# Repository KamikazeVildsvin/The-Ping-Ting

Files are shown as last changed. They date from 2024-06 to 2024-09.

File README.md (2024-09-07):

# The Ping Ting
This repository contains the KiCad files and the design files for *The Ping Ting*.

The Ping Ting is a single PCB with three different high-Q state variable filters, which are intended to be used for "filter pinging".
The board can be supplied from a typical 9V-12V DC center positive power supply.

## Images

### 3D Model
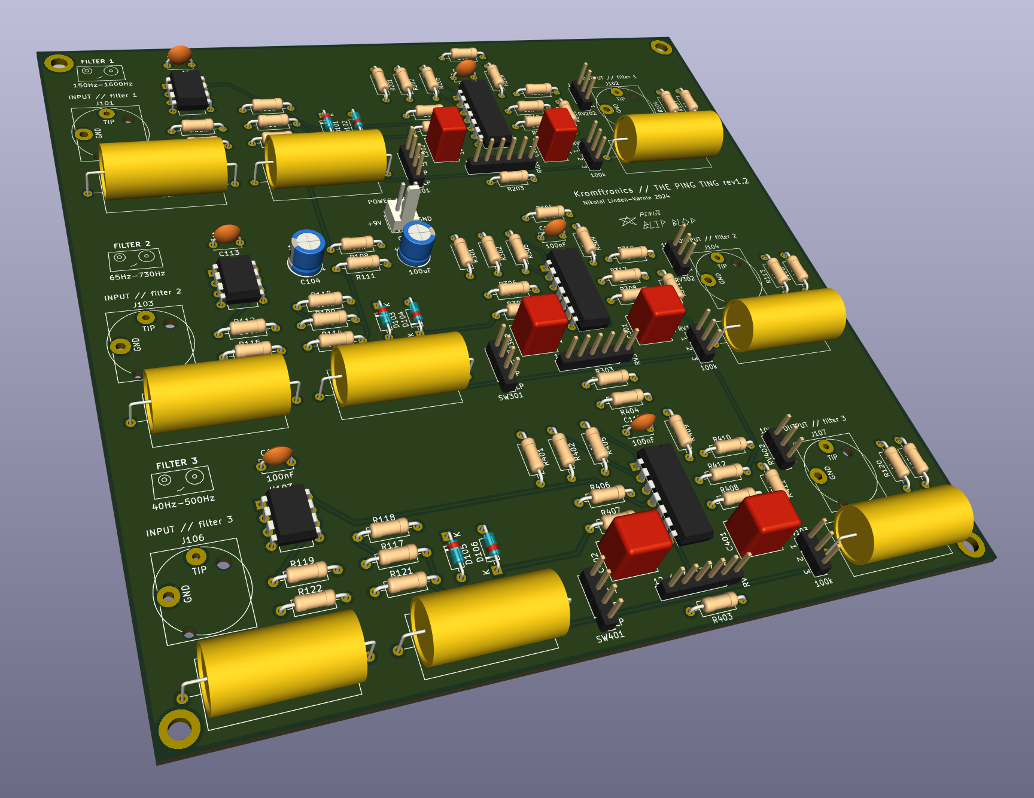
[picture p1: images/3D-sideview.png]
3D-sideview


### PCB
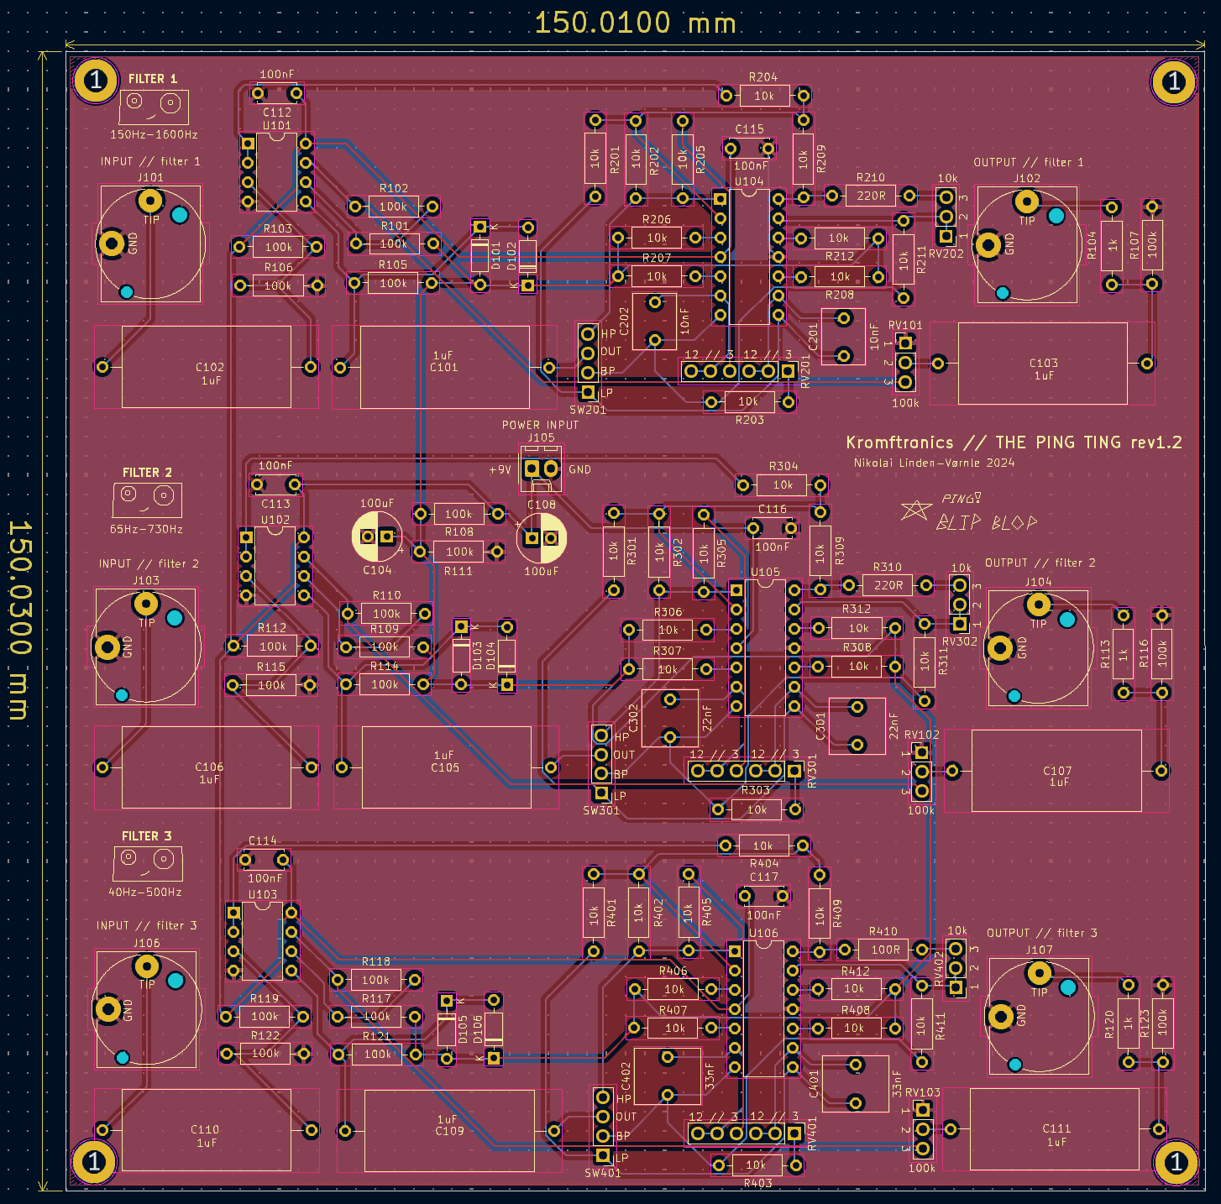
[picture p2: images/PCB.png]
PCB


### Schematic
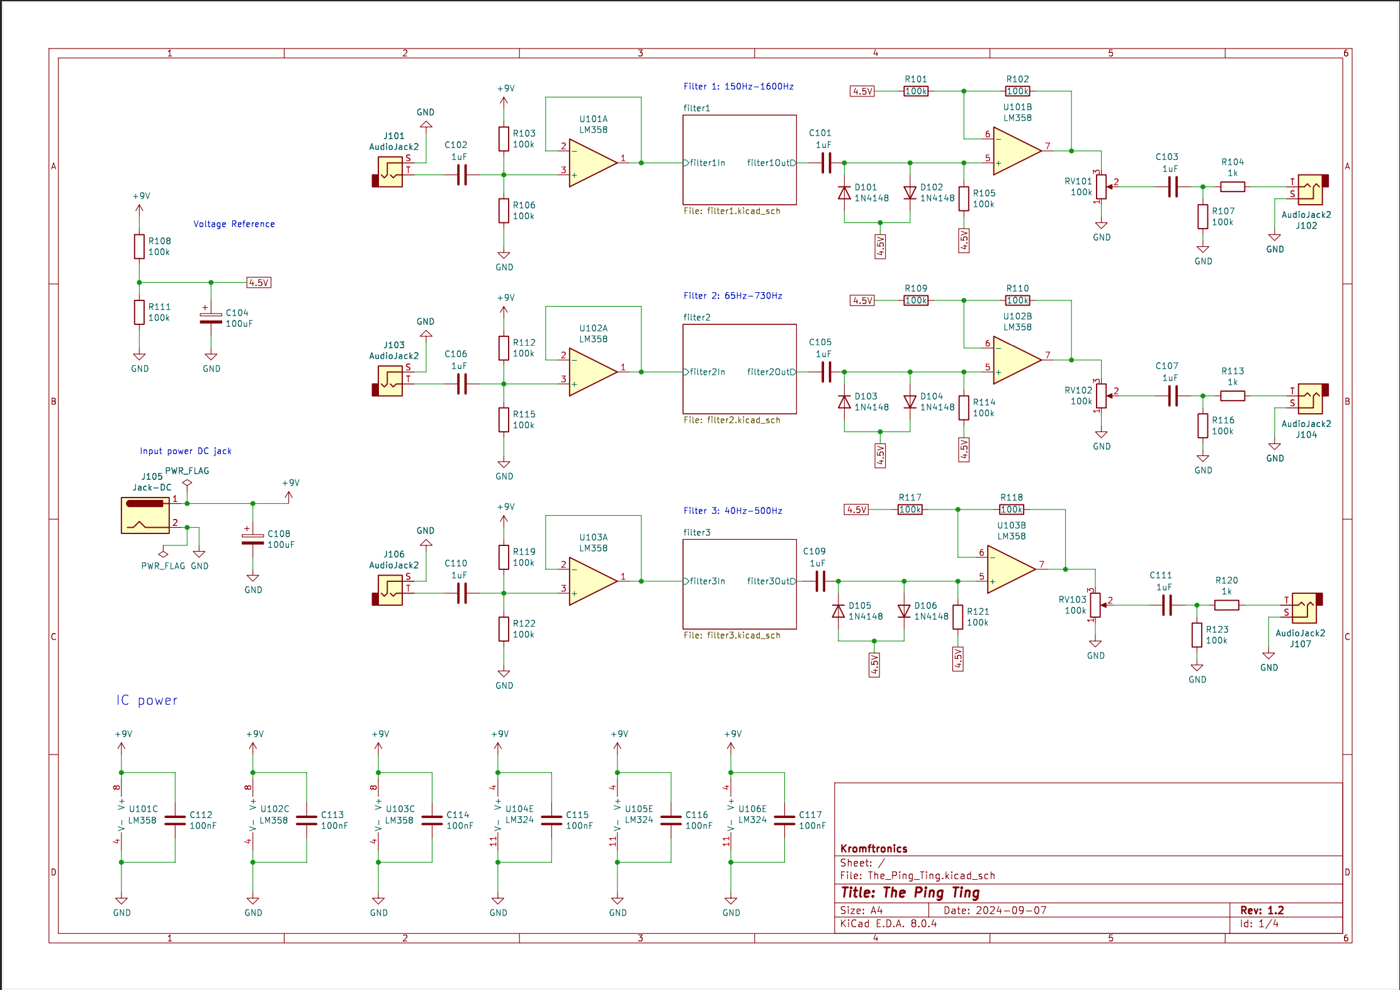
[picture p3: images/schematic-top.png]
schematic


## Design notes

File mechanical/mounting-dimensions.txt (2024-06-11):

Dimensioner til huller:

(1) Rotary Switch: 11mm

(2) Frequency Pot: 7.5mm

(3) Resonans Pot: 7.5mm

(4) Volume Pot: 11mm

Layout - ift. metalpladen

(1) (2) (3) (4)

(1) (2) (3) (4)

(1) (2) (3) (4)

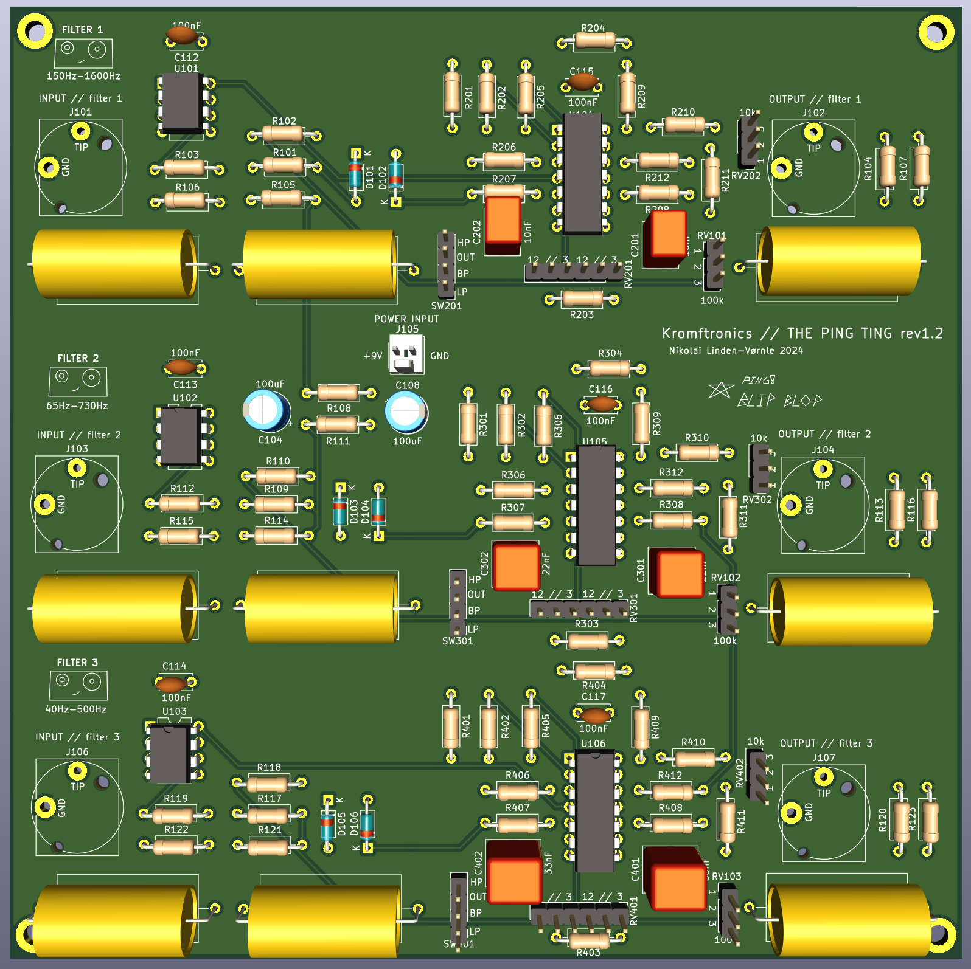
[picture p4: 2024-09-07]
images/3D.png

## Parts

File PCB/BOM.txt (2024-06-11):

BOM - The Ping Ting

LM342 [4x rail-to-rail opamps]

LM358 [2x rail-to-rail opamps]

Dual 100kOhm log potentiometer

resistors

film/ceramic caps

1P3T switches (Banzei mangler en)

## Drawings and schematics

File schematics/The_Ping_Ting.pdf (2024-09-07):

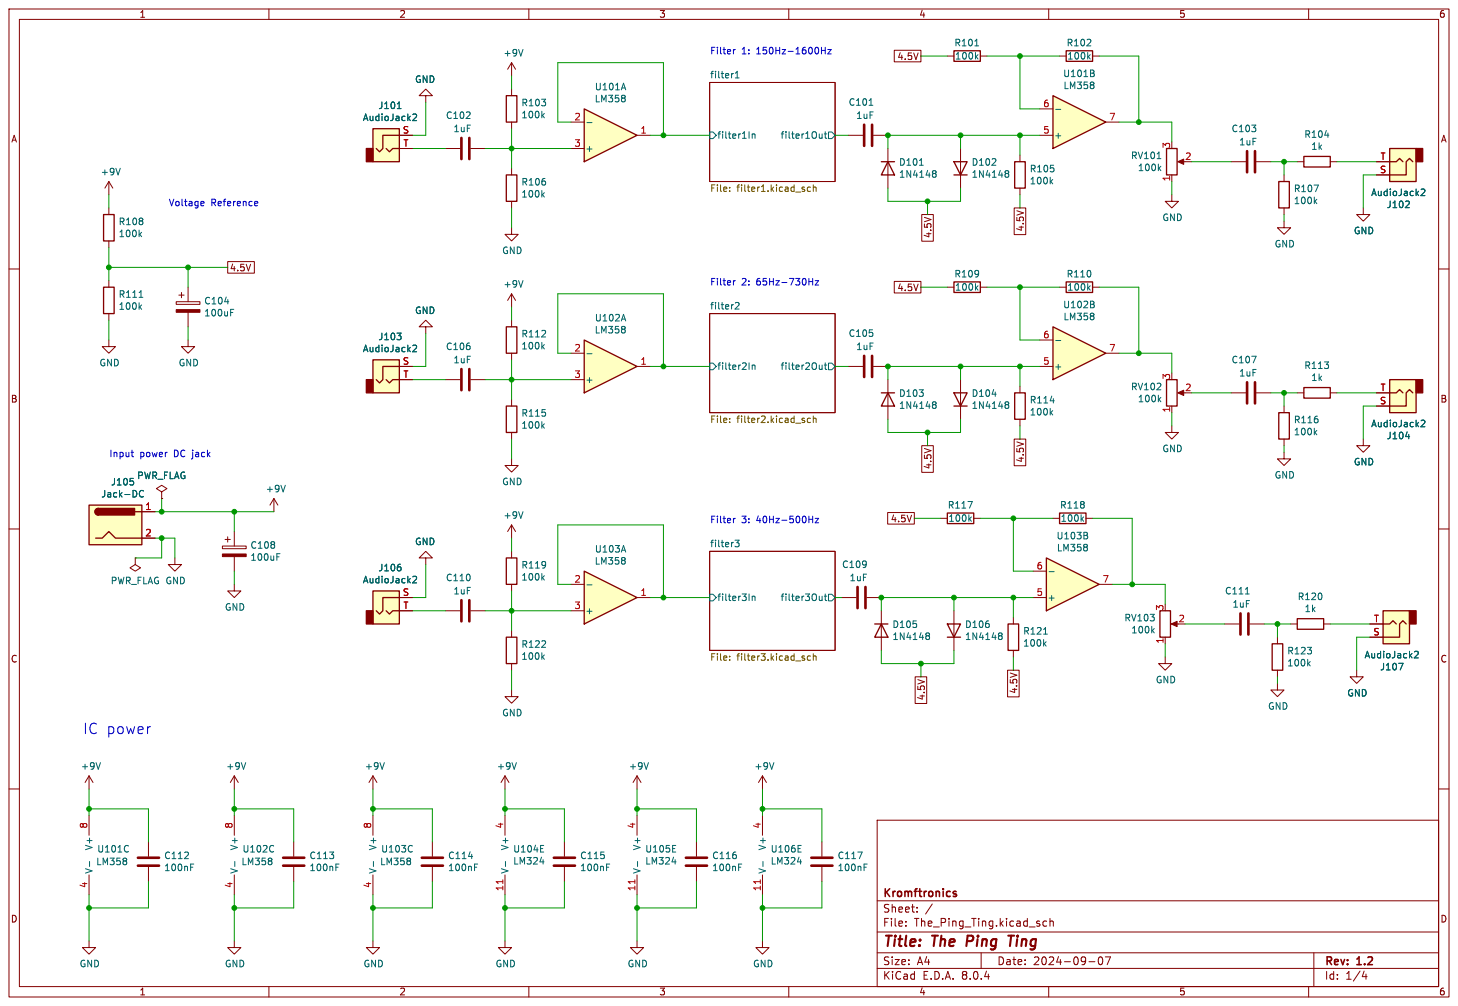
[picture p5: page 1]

Filter 2: 65Hz-730Hz Filter 3: 40Hz-500Hz Voltage Reference

Input power DC jack

Id: 1/4 Title: The Ping Ting

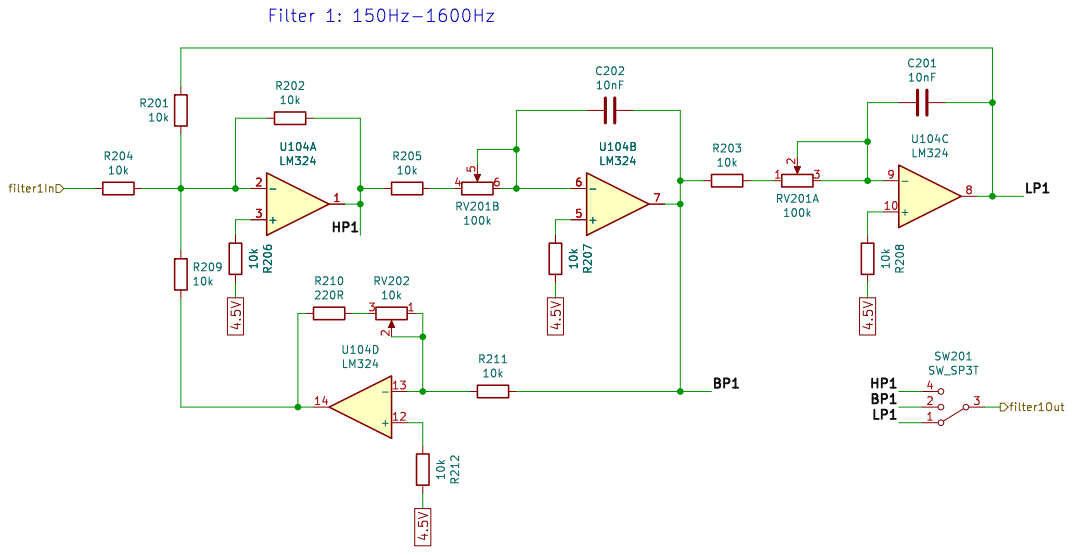
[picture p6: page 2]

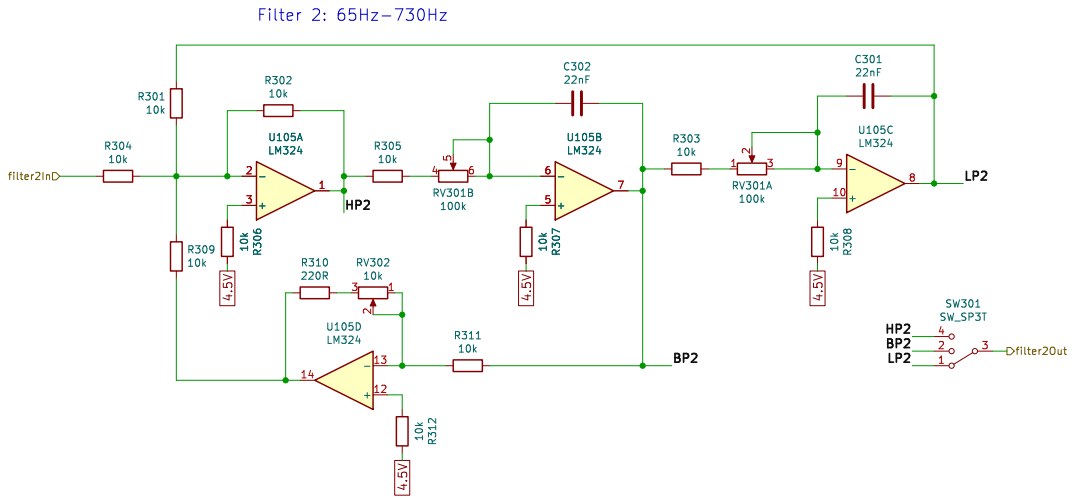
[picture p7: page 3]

Id: 3/4 Title: Mid Frequency Filter File: filter2.kicad_sch Sheet: /filter2/ Kromftronics

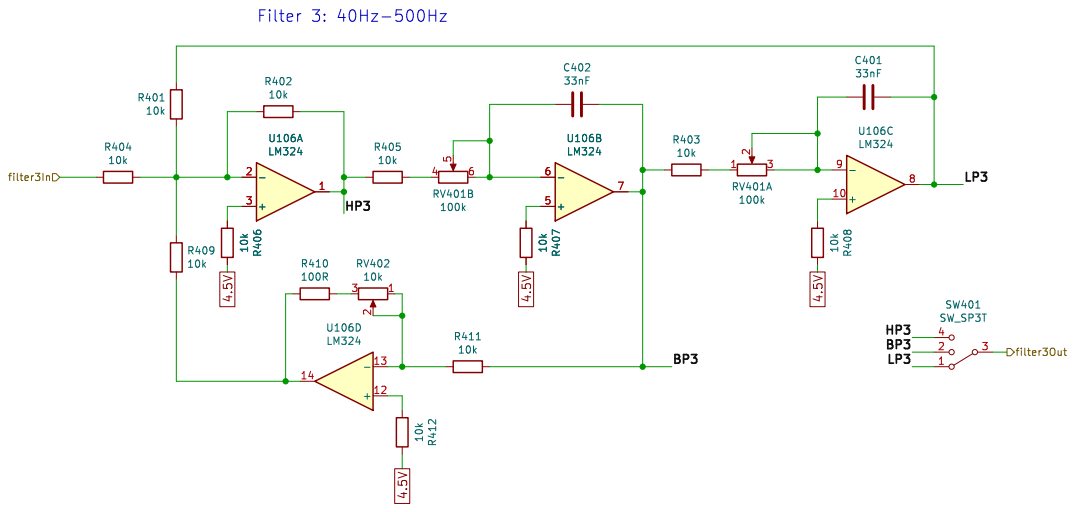
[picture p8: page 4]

Id: 4/4 Title: Low Frequency Filter File: filter3.kicad_sch Sheet: /filter3/ Kromftronics

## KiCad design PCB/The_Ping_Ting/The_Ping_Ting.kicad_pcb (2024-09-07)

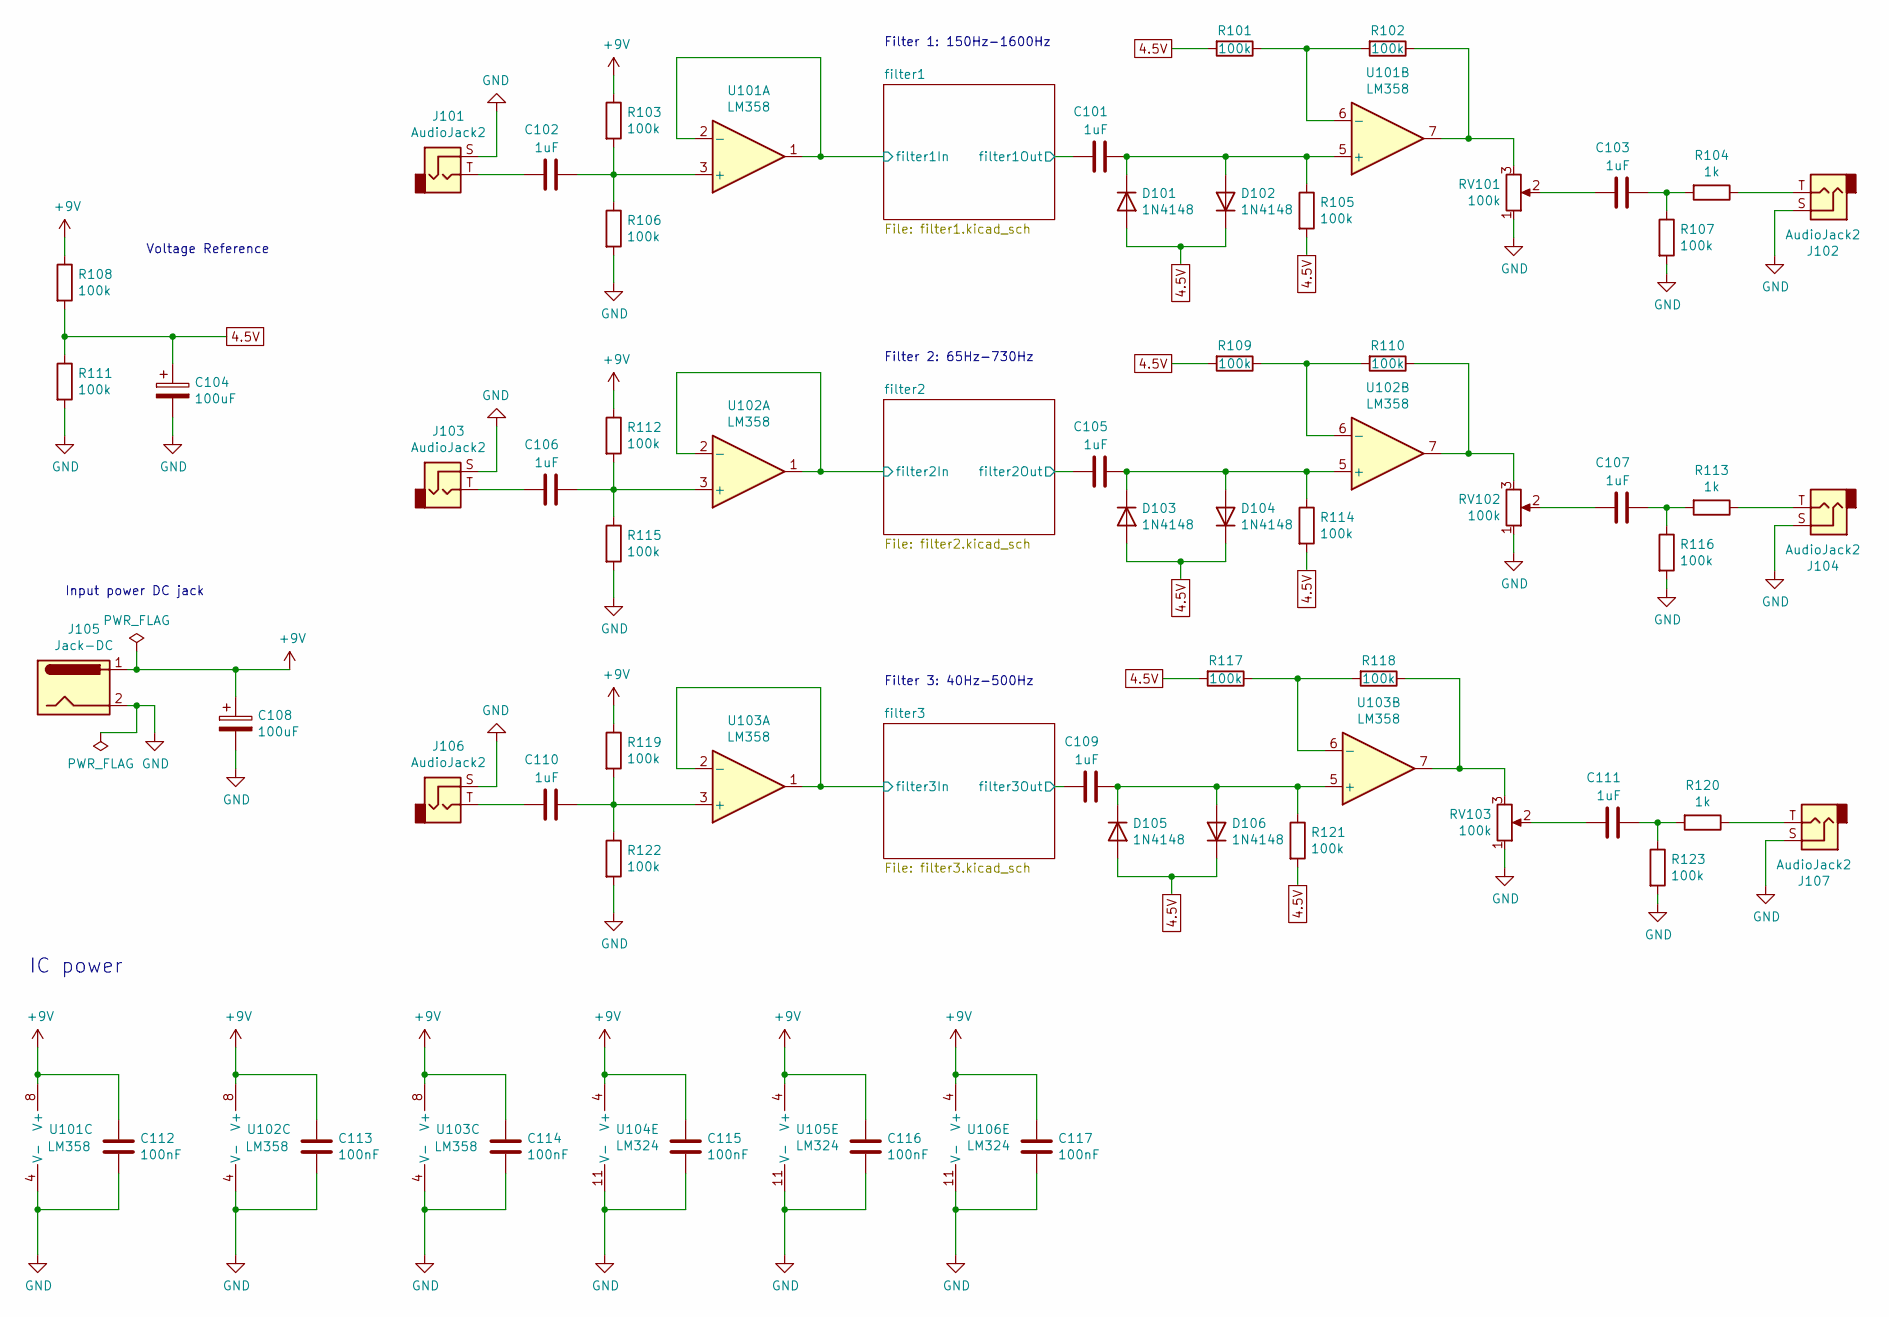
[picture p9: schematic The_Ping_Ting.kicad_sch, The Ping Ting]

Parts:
C101, C102, C103, C105, C106, C107, C109, C110, C111: 1uF; C_Axial_L22.0mm_D10.5mm_P27.50mm_Horizontal
C104, C108: 100uF; CP_Radial_D6.3mm_P2.50mm
C112, C113, C114, C115, C116, C117: 100nF; C_Disc_D5.0mm_W2.5mm_P5.00mm
D101, D102, D103, D104, D105, D106: 1N4148; D_DO-35_SOD27_P7.62mm_Horizontal
J101, J102, J103, J104, J106, J107: AudioJack2; Jack_6.35mm_Neutrik_NJ2FD-V_Vertical
J105: Jack-DC; Molex_KK-254_AE-6410-02A_1x02_P2.54mm_Vertical
R101, R102, R103, R105, R106, R107, R108, R109, R110, R111, R112, R114, R115, R116, R117, R118, R119, R121, R122, R123: 100k; R_Axial_DIN0207_L6.3mm_D2.5mm_P10.16mm_Horizontal
R104, R113, R120: 1k; R_Axial_DIN0207_L6.3mm_D2.5mm_P10.16mm_Horizontal
RV101, RV102, RV103: 100k; PinHeader_1x03_P2.54mm_Vertical
U101, U102, U103: LM358; DIP-8_W7.62mm
U104, U105, U106: LM324; DIP-14_W7.62mm

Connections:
4.5V: C104.1, D101.2 (A), D102.1 (K), D103.2 (A), D104.1 (K), D105.2 (A), D106.1 (K), R101.2, R105.2, R108.2, R109.2, R111.1, R114.2, R117.2, R121.2; also elsewhere on the board
+9V: C108.1, C112.1, C113.1, C114.1, C115.1, C116.1, C117.1, J105.1, R103.1, R108.1, R112.1, R119.1, U101.8 (V+), U102.8 (V+), U103.8 (V+), U104.4 (V+), U105.4 (V+), U106.4 (V+)
/filter1/filter1In: U101.1, U101.2 (-); also elsewhere on the board
/filter1/filter1Out: C101.1; also elsewhere on the board
/filter2/filter2In: U102.1, U102.2 (-); also elsewhere on the board
/filter2/filter2Out: C105.1; also elsewhere on the board
/filter3/filter3In: U103.1, U103.2 (-); also elsewhere on the board
/filter3/filter3Out: C109.1; also elsewhere on the board
GND: C104.2, C108.2, C112.2, C113.2, C114.2, C115.2, C116.2, C117.2, J101.S, J102.S, J103.S, J104.S, J105.2, J106.S, J107.S, R106.2, R107.2, R111.2, R115.2, R116.2, R122.2, R123.2, RV101.1, RV102.1, RV103.1, U101.4 (V-), U102.4 (V-), U103.4 (V-), U104.11 (V-), U105.11 (V-), U106.11 (V-)
unnamed: C102.1, J101.T
unnamed: C103.1, RV101.2
unnamed: C103.2, R104.2, R107.1
unnamed: C106.1, J103.T
unnamed: C107.1, RV102.2
unnamed: C107.2, R113.2, R116.1
unnamed: C110.1, J106.T
unnamed: C111.1, RV103.2
unnamed: C111.2, R120.2, R123.1
unnamed: C101.2, D101.1 (K), D102.2 (A), R105.1, U101.5 (+)
unnamed: C105.2, D103.1 (K), D104.2 (A), R114.1, U102.5 (+)
unnamed: C109.2, D105.1 (K), D106.2 (A), R121.1, U103.5 (+)
unnamed: J102.T, R104.1
unnamed: J104.T, R113.1
unnamed: J107.T, R120.1
unnamed: R102.1, RV101.3, U101.7
unnamed: R110.1, RV102.3, U102.7
unnamed: R118.1, RV103.3, U103.7
unnamed: C102.2, R103.2, R106.1, U101.3 (+)
unnamed: R101.1, R102.2, U101.6 (-)
unnamed: C106.2, R112.2, R115.1, U102.3 (+)
unnamed: R109.1, R110.2, U102.6 (-)
unnamed: C110.2, R119.2, R122.1, U103.3 (+)
unnamed: R117.1, R118.2, U103.6 (-)

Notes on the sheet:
Filter 1: 150Hz-1600Hz
IC power
Input power DC jack
Filter 3: 40Hz-500Hz
Filter 2: 65Hz-730Hz
Voltage Reference

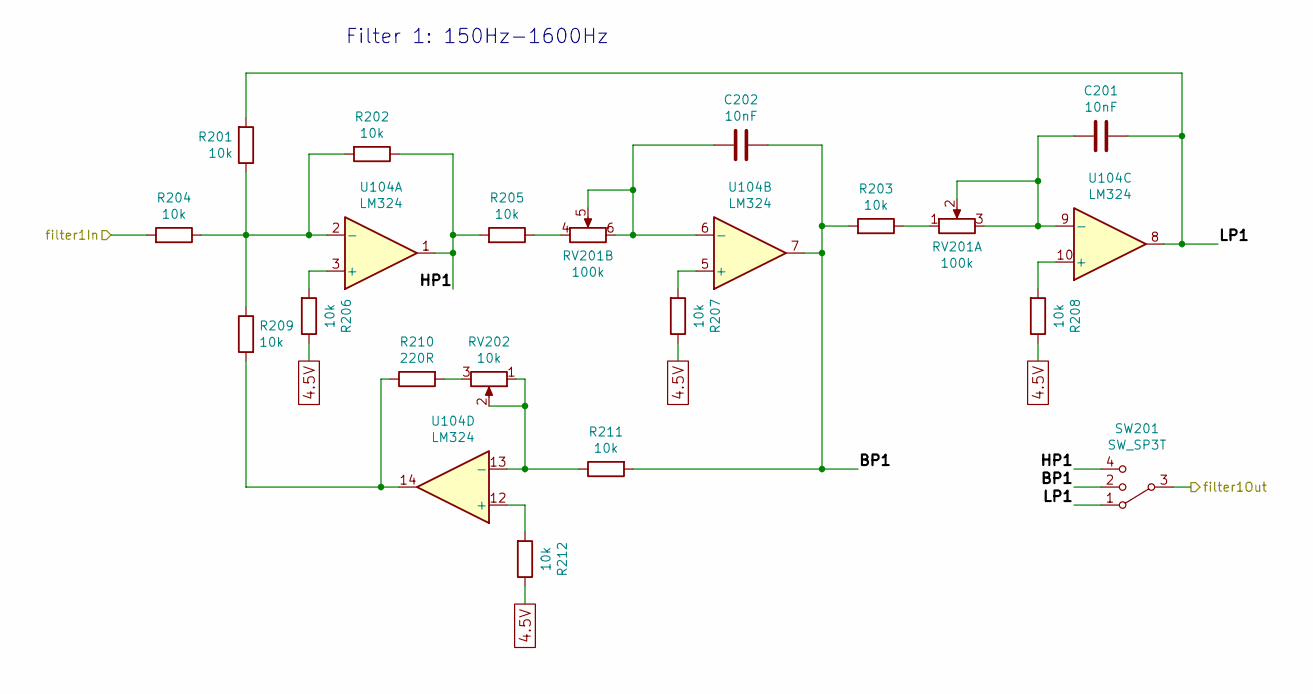
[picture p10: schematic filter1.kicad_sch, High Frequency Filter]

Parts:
C201, C202: 10nF; C_Rect_L7.2mm_W5.5mm_P5.00mm_FKS2_FKP2_MKS2_MKP2
R201, R202, R203, R204, R205, R206, R207, R208, R209, R211, R212: 10k; R_Axial_DIN0207_L6.3mm_D2.5mm_P10.16mm_Horizontal
R210: 220R; R_Axial_DIN0207_L6.3mm_D2.5mm_P10.16mm_Horizontal
RV201: 100k; PinHeader_1x06_P2.54mm_Vertical
RV202: 10k; PinHeader_1x03_P2.54mm_Vertical
SW201: SW_SP3T; PinHeader_1x04_P2.54mm_Vertical
U104: LM324; DIP-14_W7.62mm

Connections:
4.5V: R206.1, R207.1, R208.1, R212.1; also elsewhere on the board
/filter1/BP1: C202.1, R203.2, R211.2, SW201.2, U104.7
/filter1/HP1: R202.1, R205.2, SW201.4, U104.1
/filter1/LP1: C201.1, R201.2, SW201.1, U104.8
/filter1/filter1In: R204.2; also elsewhere on the board
/filter1/filter1Out: SW201.3; also elsewhere on the board
unnamed: R203.1, RV201.1
unnamed: R205.1, RV201.4
unnamed: R209.2, R210.1, U104.14
unnamed: R210.2, RV202.3
unnamed: R206.2, U104.3 (+)
unnamed: R201.1, R202.2, R204.1, R209.1, U104.2 (-)
unnamed: R207.2, U104.5 (+)
unnamed: C202.2, RV201.5, RV201.6, U104.6 (-)
unnamed: R208.2, U104.10 (+)
unnamed: C201.2, RV201.2, RV201.3, U104.9 (-)
unnamed: R212.2, U104.12 (+)
unnamed: R211.1, RV202.1, RV202.2, U104.13 (-)

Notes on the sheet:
Filter 1: 150Hz-1600Hz

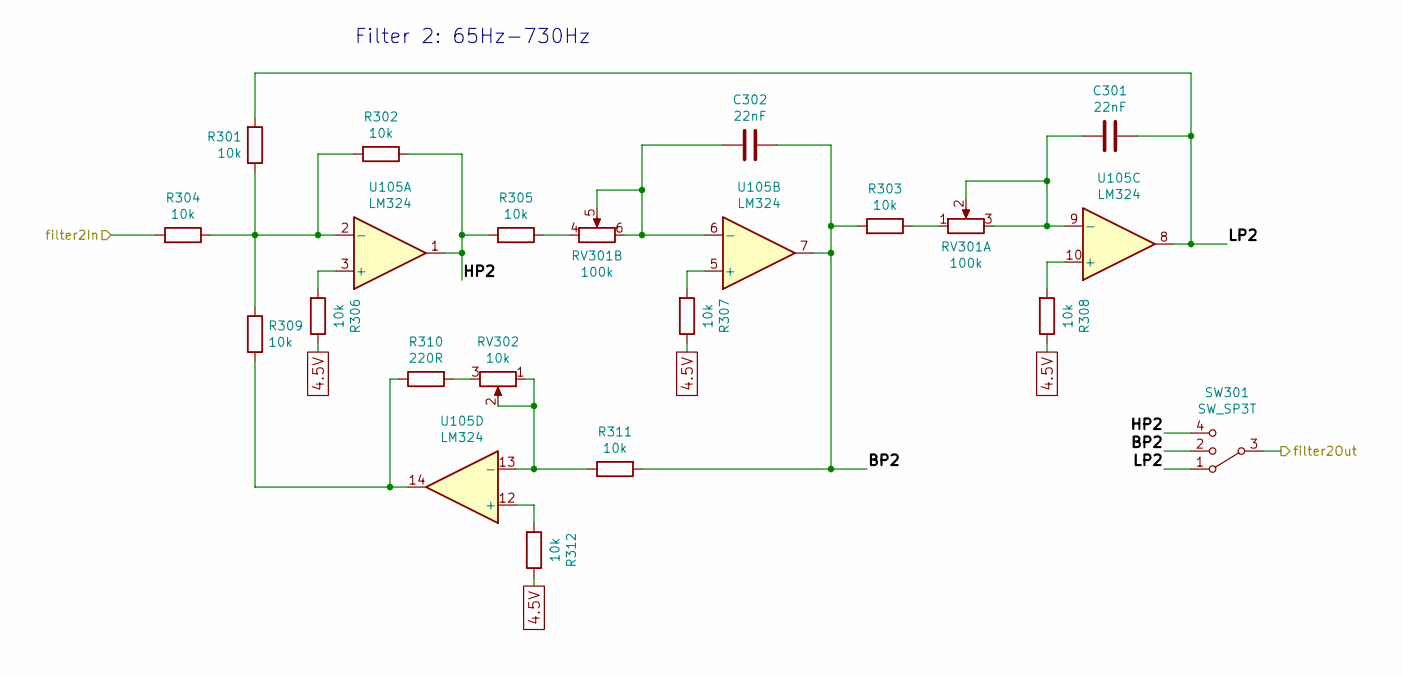
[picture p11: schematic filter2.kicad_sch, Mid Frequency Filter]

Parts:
C301, C302: 22nF; C_Rect_L7.2mm_W7.2mm_P5.00mm_FKS2_FKP2_MKS2_MKP2
R301, R302, R303, R304, R305, R306, R307, R308, R309, R311, R312: 10k; R_Axial_DIN0207_L6.3mm_D2.5mm_P10.16mm_Horizontal
R310: 220R; R_Axial_DIN0207_L6.3mm_D2.5mm_P10.16mm_Horizontal
RV301: 100k; PinHeader_1x06_P2.54mm_Vertical
RV302: 10k; PinHeader_1x03_P2.54mm_Vertical
SW301: SW_SP3T; PinHeader_1x04_P2.54mm_Vertical
U105: LM324; DIP-14_W7.62mm

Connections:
4.5V: R306.1, R307.1, R308.1, R312.1; also elsewhere on the board
/filter2/BP2: C302.1, R303.2, R311.2, SW301.2, U105.7
/filter2/HP2: R302.1, R305.2, SW301.4, U105.1
/filter2/LP2: C301.1, R301.2, SW301.1, U105.8
/filter2/filter2In: R304.2; also elsewhere on the board
/filter2/filter2Out: SW301.3; also elsewhere on the board
unnamed: R303.1, RV301.1
unnamed: R305.1, RV301.4
unnamed: R309.2, R310.1, U105.14
unnamed: R310.2, RV302.3
unnamed: R306.2, U105.3 (+)
unnamed: R301.1, R302.2, R304.1, R309.1, U105.2 (-)
unnamed: R307.2, U105.5 (+)
unnamed: C302.2, RV301.5, RV301.6, U105.6 (-)
unnamed: R308.2, U105.10 (+)
unnamed: C301.2, RV301.2, RV301.3, U105.9 (-)
unnamed: R312.2, U105.12 (+)
unnamed: R311.1, RV302.1, RV302.2, U105.13 (-)

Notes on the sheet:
Filter 2: 65Hz-730Hz

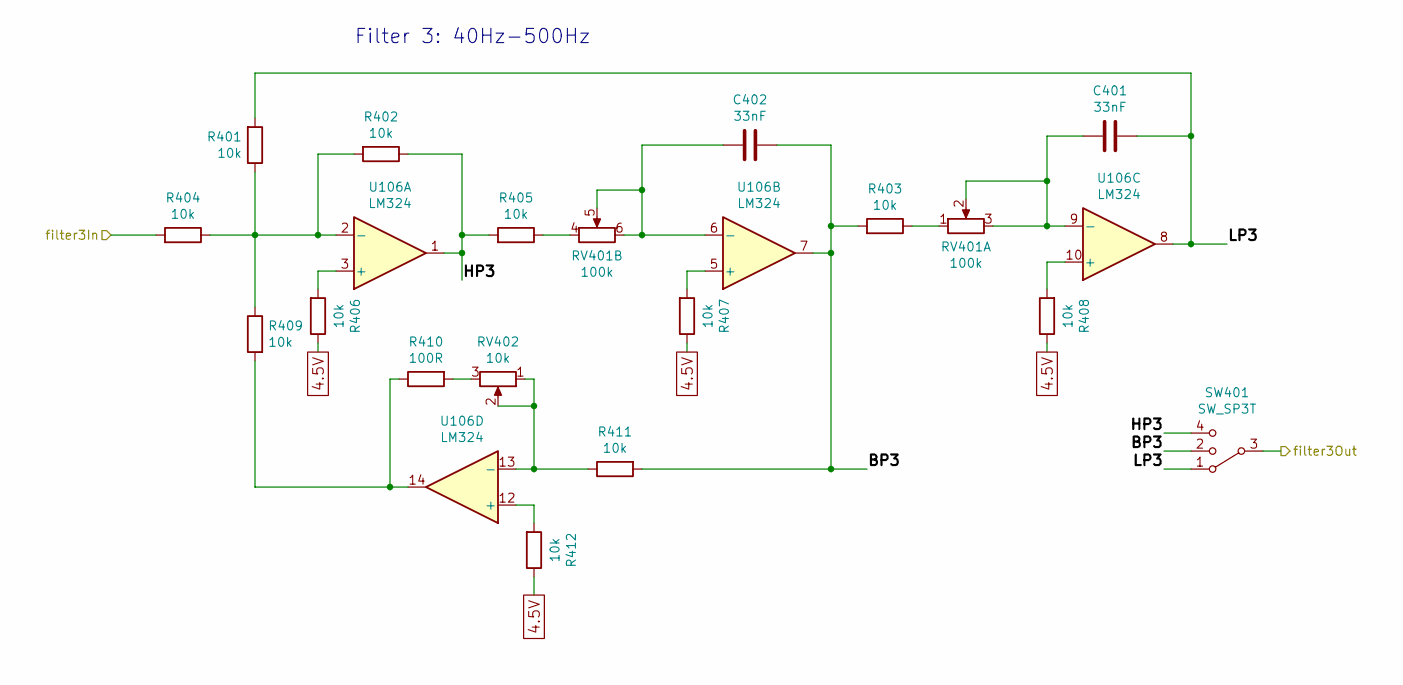
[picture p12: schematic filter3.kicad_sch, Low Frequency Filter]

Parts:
C401, C402: 33nF; C_Rect_L7.2mm_W8.5mm_P5.00mm_FKP2_FKP2_MKS2_MKP2
R401, R402, R403, R404, R405, R406, R407, R408, R409, R411, R412: 10k; R_Axial_DIN0207_L6.3mm_D2.5mm_P10.16mm_Horizontal
R410: 100R; R_Axial_DIN0207_L6.3mm_D2.5mm_P10.16mm_Horizontal
RV401: 100k; PinHeader_1x06_P2.54mm_Vertical
RV402: 10k; PinHeader_1x03_P2.54mm_Vertical
SW401: SW_SP3T; PinHeader_1x04_P2.54mm_Vertical
U106: LM324; DIP-14_W7.62mm

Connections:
4.5V: R406.1, R407.1, R408.1, R412.1; also elsewhere on the board
/filter3/BP3: C402.1, R403.2, R411.2, SW401.2, U106.7
/filter3/HP3: R402.1, R405.2, SW401.4, U106.1
/filter3/LP3: C401.1, R401.2, SW401.1, U106.8
/filter3/filter3In: R404.2; also elsewhere on the board
/filter3/filter3Out: SW401.3; also elsewhere on the board
unnamed: R403.1, RV401.1
unnamed: R405.1, RV401.4
unnamed: R409.2, R410.1, U106.14
unnamed: R410.2, RV402.3
unnamed: R406.2, U106.3 (+)
unnamed: R401.1, R402.2, R404.1, R409.1, U106.2 (-)
unnamed: R407.2, U106.5 (+)
unnamed: C402.2, RV401.5, RV401.6, U106.6 (-)
unnamed: R408.2, U106.10 (+)
unnamed: C401.2, RV401.2, RV401.3, U106.9 (-)
unnamed: R412.2, U106.12 (+)
unnamed: R411.1, RV402.1, RV402.2, U106.13 (-)

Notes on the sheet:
Filter 3: 40Hz-500Hz

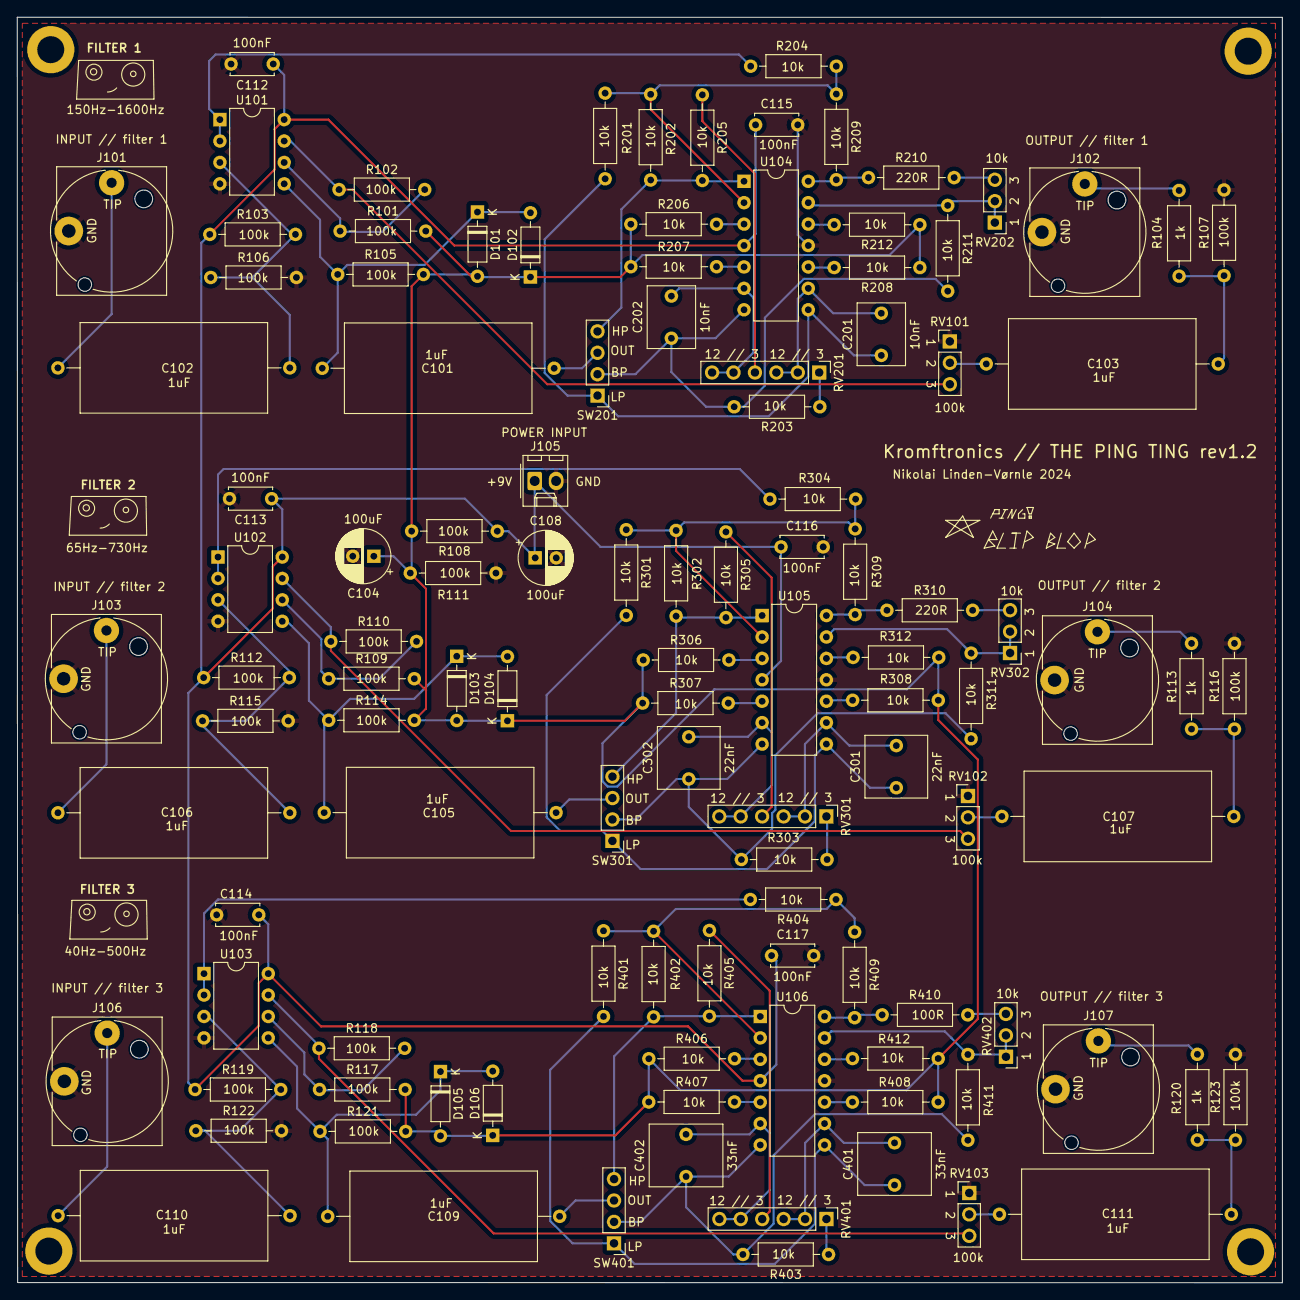
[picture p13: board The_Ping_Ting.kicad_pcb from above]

Board: 2 copper layers, 150.0 x 150.1 mm, 113 parts (0 on the bottom side), 78 nets.

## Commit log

2024-06-11 initial commit.
    [The_Ping_Ting.kicad_pcb, The_Ping_Ting.kicad_sch, filter1.kicad_sch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]
2024-06-11 added images of PCB, 3D model and schematic.
    [The_Ping_Ting.kicad_pcb, The_Ping_Ting.kicad_sch, filter1.kicad_sch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]
2024-09-07 REVV 1.2 - Updated resonance feedback resistance Updated the feedback resistance in the mid and high frequency feedback circuit to get a more "stable" resonance level.
    [The_Ping_Ting.kicad_pcb, The_Ping_Ting.kicad_sch, filter1.kicad_sch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]
